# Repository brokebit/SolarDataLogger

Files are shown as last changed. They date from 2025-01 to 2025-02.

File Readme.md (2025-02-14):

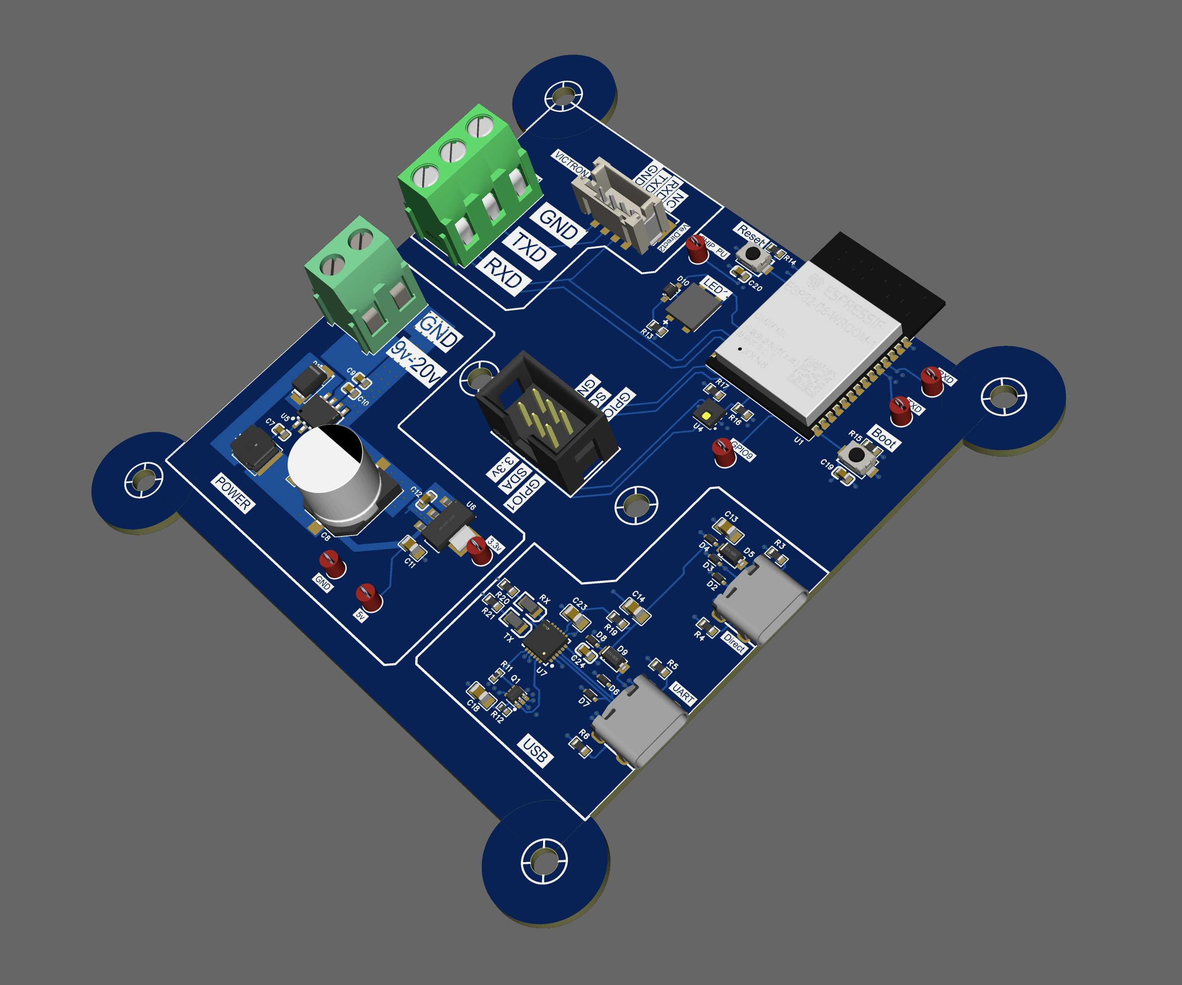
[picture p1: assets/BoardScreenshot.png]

# This repo has submodules
- To clone: git clone --recurse-submodules -j8 REPO_URL
- To pull latest versin: git pull --recurse-submodules

# What is all this

Firmware for custom data logger for Victron MPPT charge controllers via the Ve.Direct port/protocol.

## Features
- Power via 9v-20v input or USB
- ESP32-C6 RISC-V CPU
- Wifi 6 support and provisioning credentials via BLE
- Receive, parse, and publish data from a Victron MPPT controller
- Publishes: panel voltage, battery voltage, panel current, battery current, serial number, etc
- Publish data via MQTT in InfluxDB line protocol format
- Onboard temperature and humidity sensors (AHT20)
- Support for optional add on board with current sensor (INA226) and solid state relay (CMX60D10)
- WS2812 LED for status information
- CP2102N USB Uart for programing and logging
- USB port direct to ESP32-C6
- Remote control via MQTT command channel

## Supported Victron MPPT Controllers

Supports both the smaller MPPT controllers that have load output and control:

- MPPT 75/10
- MPPT 75/15
- MPPT 100/10
- MPPT 100/20

Also support larger MPPT controllers without load output via a INA226 Current sensor on an add-on board:

- MPPT 100/30
- MPPT 100/50
- MPPT 150/35
- MPPT 150/45
- MPPT 150/60
- MPPT 250/70

## The Details
This is a Platform IO project. Last tested with ESP IDF 5.3.1

- /lib contains drivers and victron parser
- /src contains main program

Edit platform.ini to set some global variables and config parameters. 
- INA226_PRESENT: Set this to one if you have a INA226 connected. Otherwise 0. 
- AHT20_PRESENT: Set this to 1 if you have a AHT20 connected. Otherwise 0.
- SENSOR_LOCATION: Set this to any string you want. It will be included in the mqtt message. No more than 24 characters
- SENSOR_TYPE: Set this to whatever you want. i.e. ESP32-C6 or ESP32-S3. No more than 24 characters
           

# MQTT

## Channels
- Influx data is sent to MQTT_TOPIC
- Command should be submitted to the channel named mac address + "-cmd" i.e. FFEEDDCCBBAA-cmd 
- Commands responses are sent to the channel named mac address. i.e. FFEEDDCCBBAA

## Support remote MQTT Commands
- ota - Perform an OTA Update
- rbk - Roll back to previous version 
- rst - Reboot
- png - Get a pong back
- tmp - Get current temp in C
- hum - Get current humidity
- mem - Get free heap memory
- ver - Get firmware version

# OTA
- Firmware is download via https from any URL. The firmware looks for a file that is the mac address in all caps. 
- Firmware URL is defined in : OTA_BASE_URL (without the filename)
- Rememeber you need to configure partitions.csv 1mb partition is not enough. 

# WiFi Provisioning
- To make a QR Code for provisioning use the following JSON string and fill in appropriate values:
```{"ver":"v1","name":"PROV_123456","pop":"abcd12345","transport":"ble"}```
- Use the mobile app called "ESP BLE Provisioning"
- In menuconfig make sure that: Component config -> Bluetooth -> Bluetooth controller -> Controller Options is set to BLE not Dual Mode.

# What can you do with it? 

## Grafana Dashboard Example
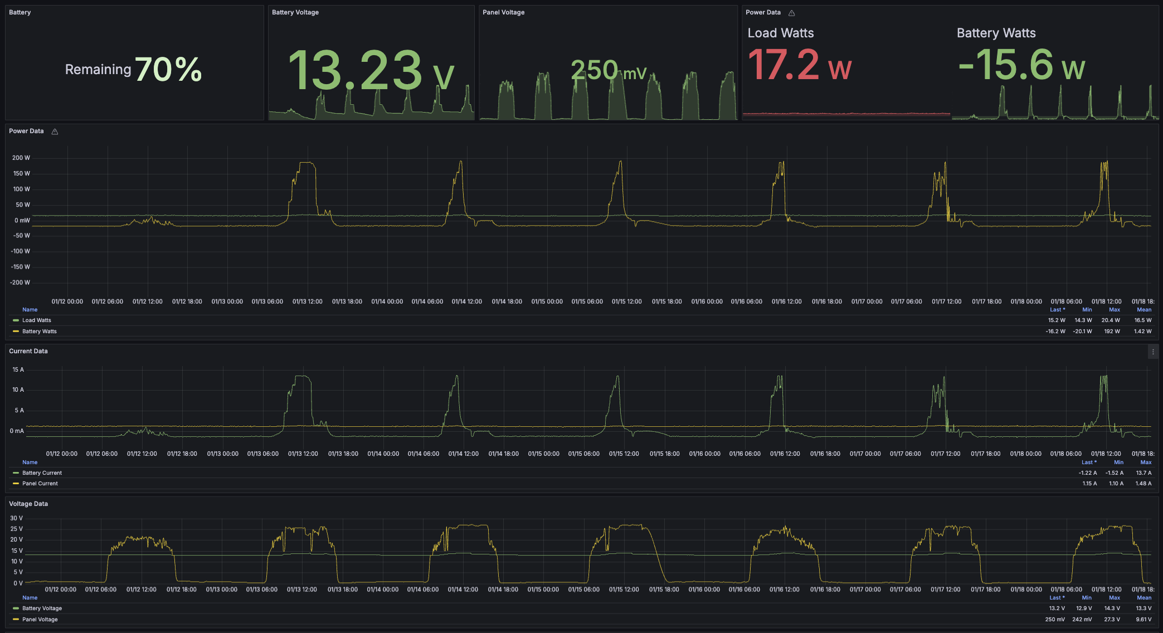
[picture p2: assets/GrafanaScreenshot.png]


# To Do
- Fix math for INA226 current sensor and address twos compliment
- CMX60D10 Relay Driver
- Some way to configure it without recompiling 
- Redo design in KiCad instead of EasyEDA and add to repo
- Finish add onboard with INA226 and CMX60D10
- Code clean up. Comments, proper error handling, review memory managment, null point checks, etc
- Add remote commands for reading voltage and current data
- MQTT TLS Support

# Done
- WS2812 Driver
- OTA Updates
- Wifi Provisioning via BLE

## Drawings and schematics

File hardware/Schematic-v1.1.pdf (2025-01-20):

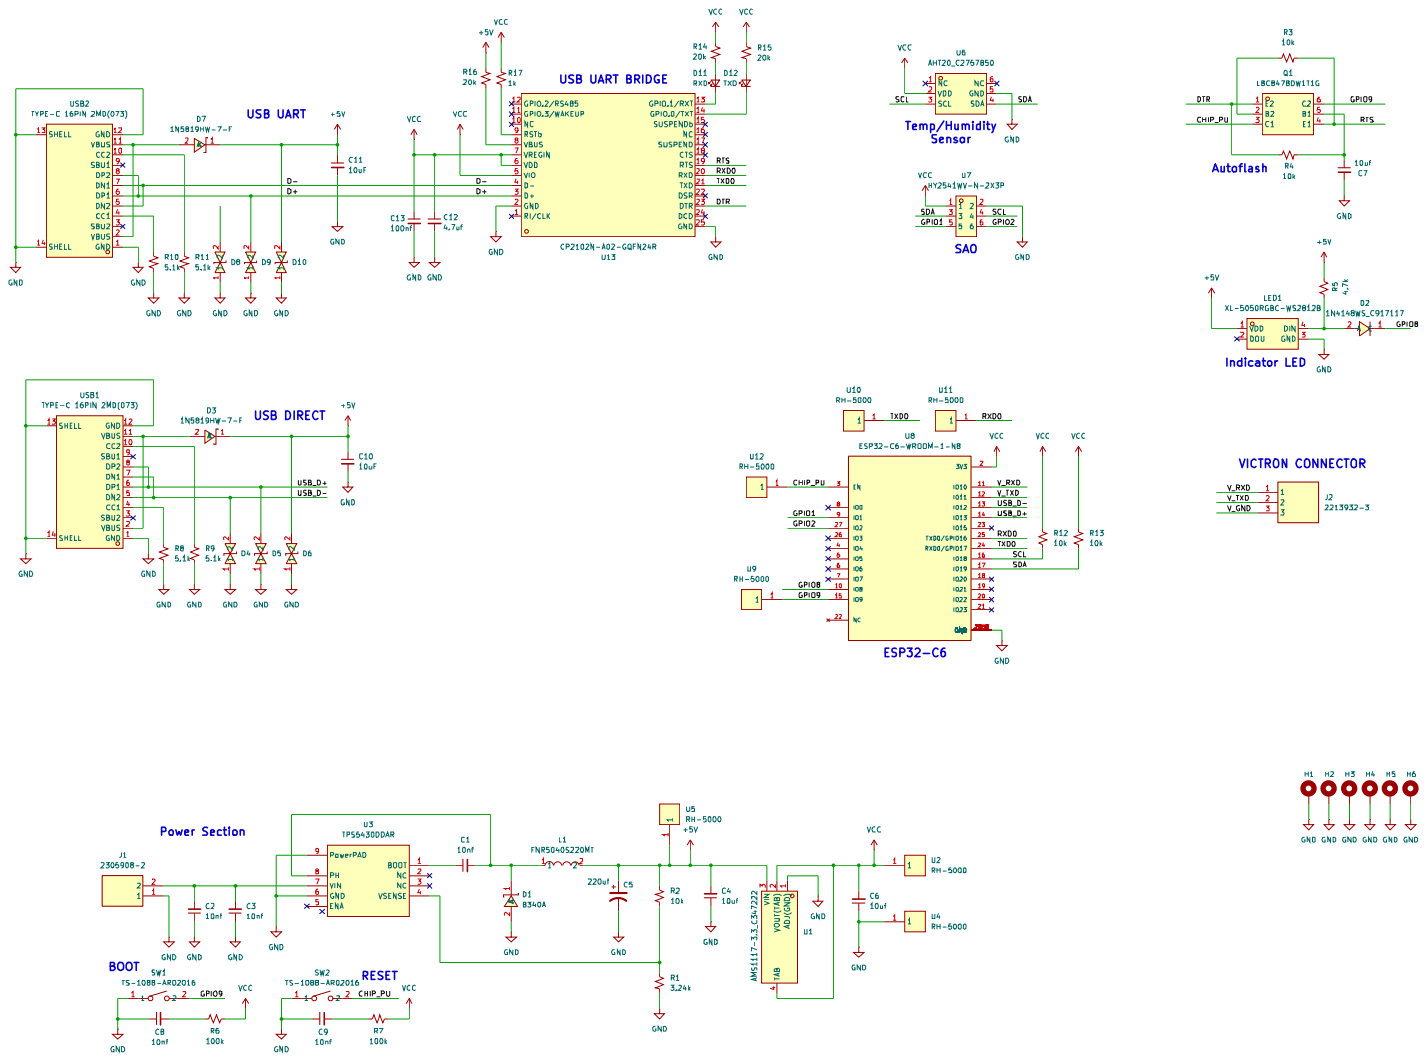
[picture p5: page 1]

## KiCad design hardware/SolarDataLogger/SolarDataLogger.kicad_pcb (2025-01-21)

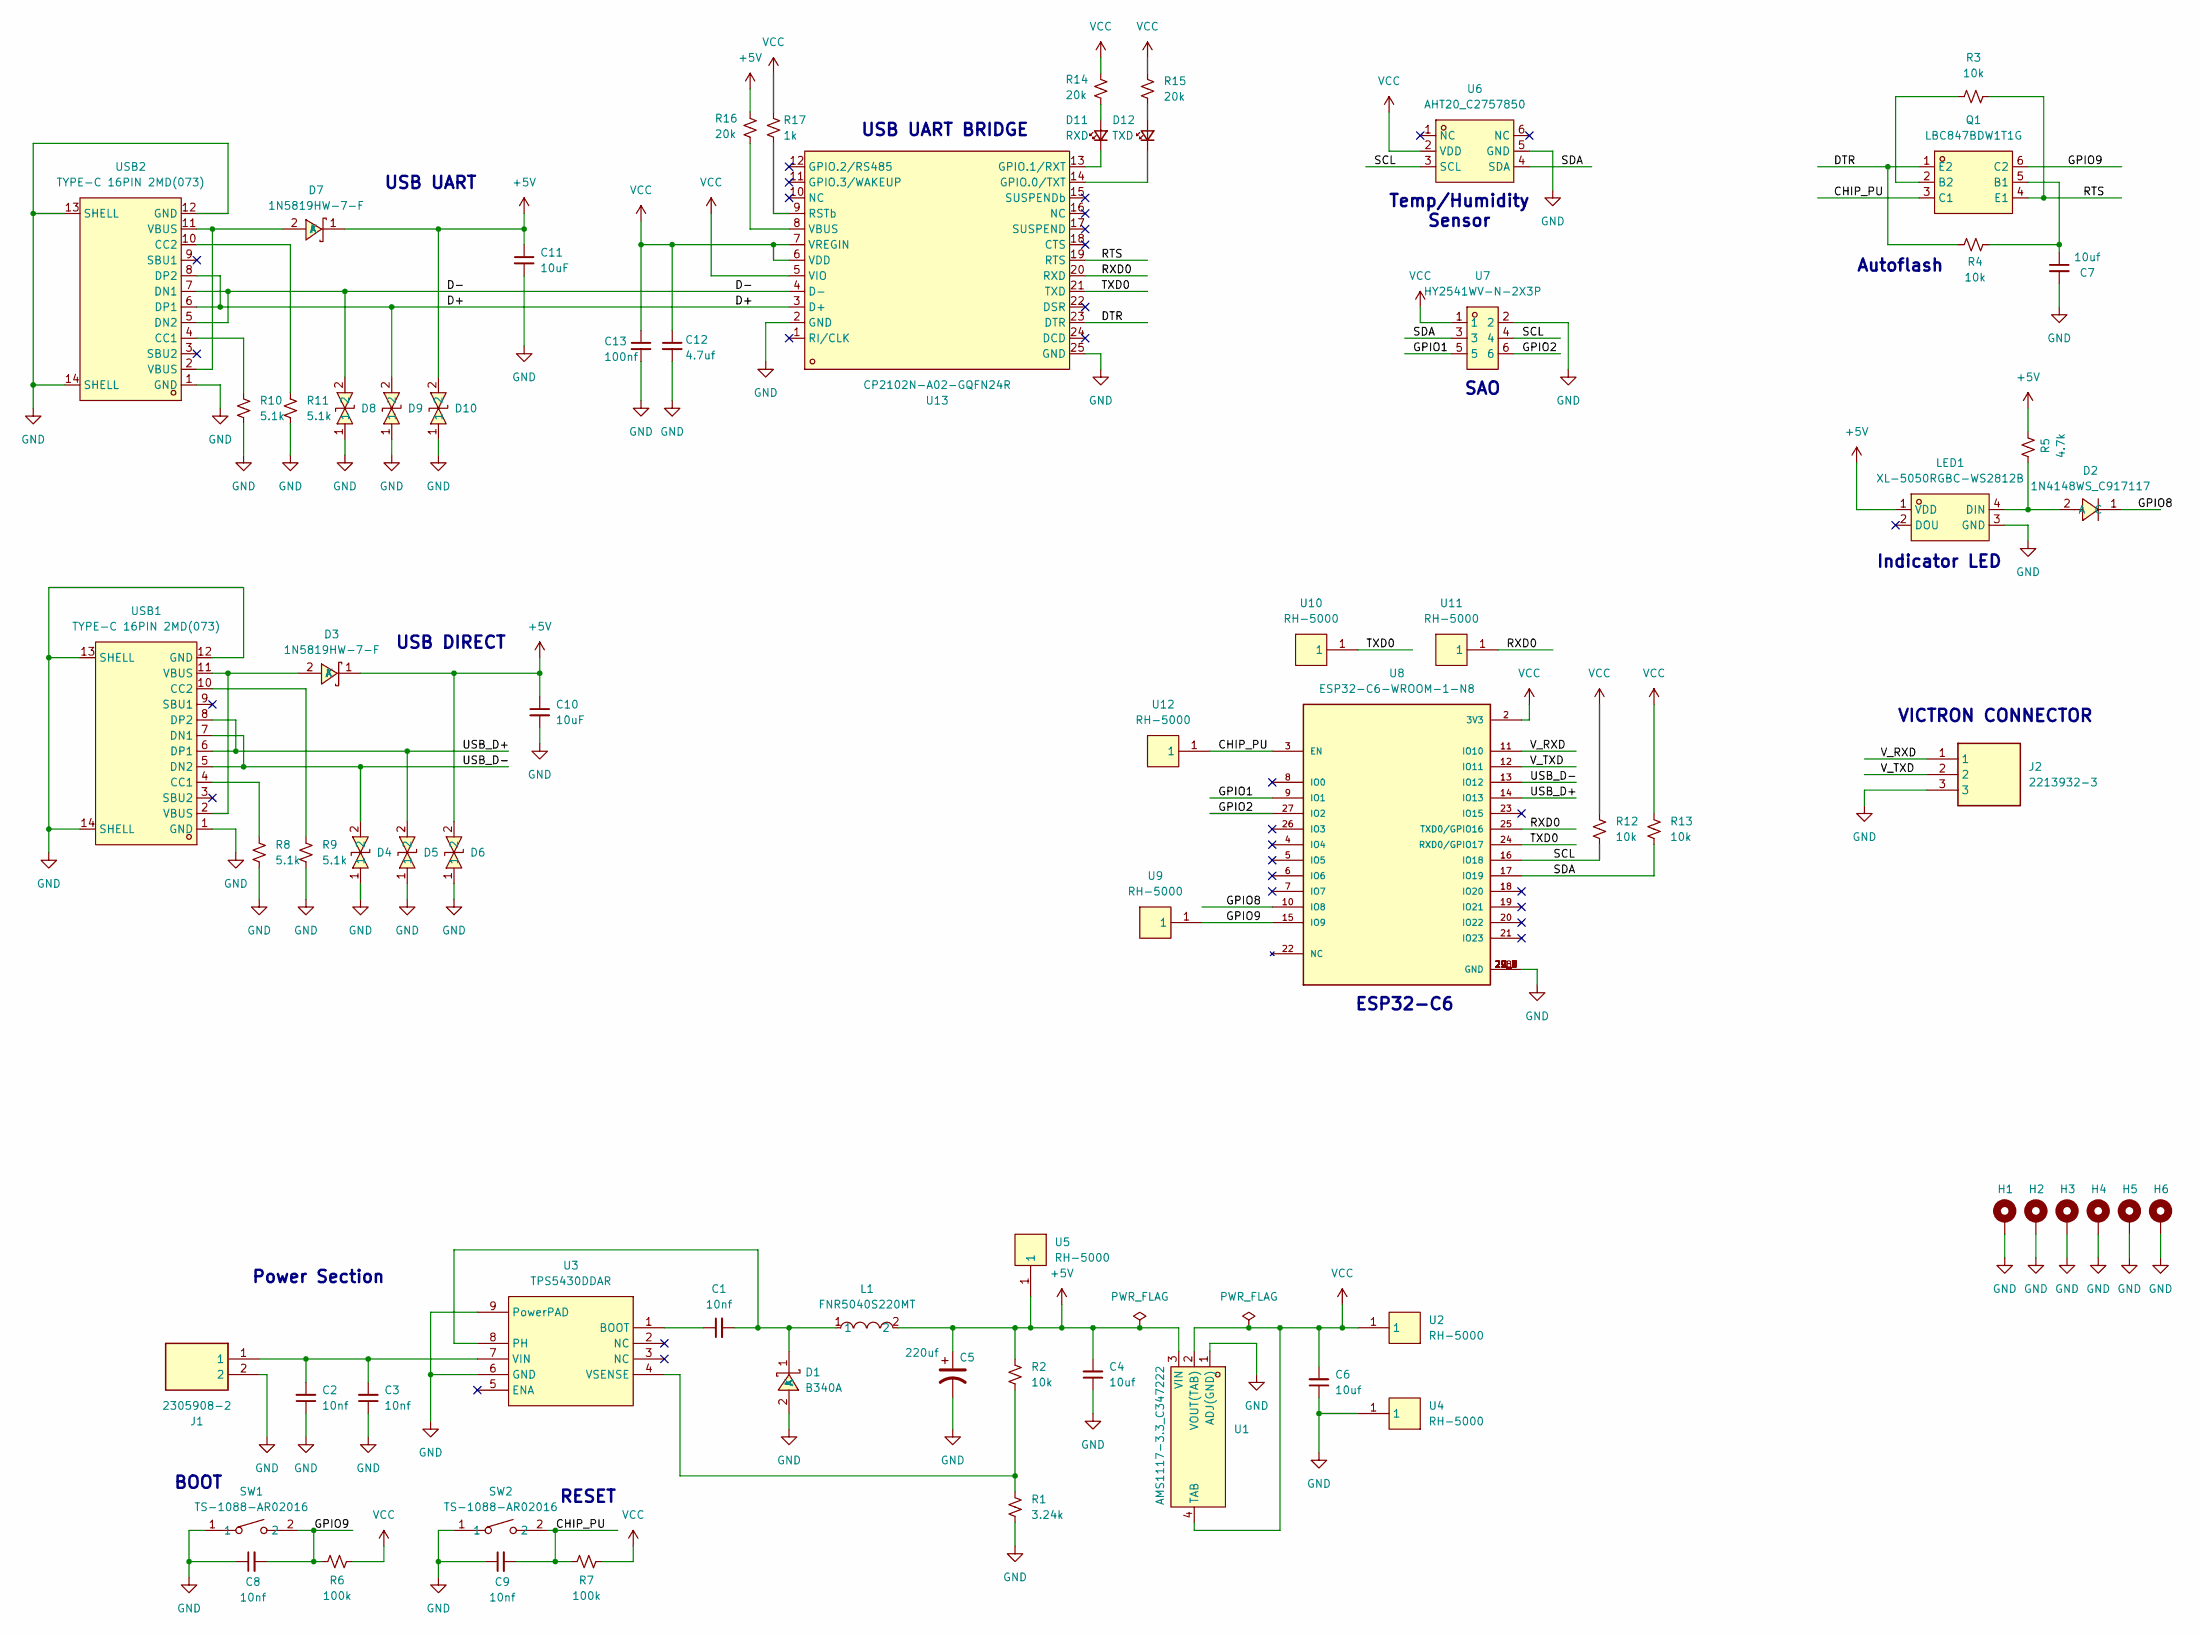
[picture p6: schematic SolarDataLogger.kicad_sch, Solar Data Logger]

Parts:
C1, C2, C3, C8, C9: 10nf; C_0603_1608Metric
C4, C6, C7: 10uf; C_0603_1608Metric
C5: 220uf; CAP-SMD_BD10.0-L10.3-W10.3-LS11.3-FD
C10, C11: 10uF; C_0603_1608Metric
C12: 4.7uf; C_0603_1608Metric
C13: 100nf; C_0603_1608Metric
D1: B340A; SMA_L4.3-W2.6-LS5.1-RD; LCSC Part C64982
D2: 1N4148WS_C917117; SOD-323_L1.8-W1.3-LS2.5-RD; LCSC Part C917117
D3, D7: 1N5819HW-7-F; SOD-123_L2.7-W1.6-LS3.7-RD; LCSC Part C82544
D4, D5, D6, D8, D9, D10: LESD5D5.0CT1G; SOD-523_L1.2-W0.8-LS1.6-BI; LCSC Part C383211
D11: RXD; LED_0603_1608Metric
D12: TXD; LED_0603_1608Metric
H1, H2, H3, H4, H5, H6: MountingHole_Pad; MountingHole_3.5mm_Pad_TopBottom
J1: 2305908-2; 23059082; Mouser Part Number 571-2305908-2
J2: 2213932-3; 22139323; Mouser Part Number 571-2213932-3
L1: FNR5040S220MT; IND-SMD_L5.0-W5.0; LCSC Part C167971
LED1: XL-5050RGBC-WS2812B; LED-SMD_4P-L5.0-W5.0-BL_XL-5050RGBC; LCSC Part C2843785
Q1: LBC847BDW1T1G; SOT-363_L2.0-W1.3-P0.65-LS2.1-BR; LCSC Part C383191
R1: 3.24k; R_0603_1608Metric
R2, R3, R4, R12, R13: 10k; R_0603_1608Metric
R5: 4.7k; R_0603_1608Metric
R6, R7: 100k; R_0603_1608Metric
R8, R9, R10, R11: 5.1k; R_0603_1608Metric
R14, R15, R16: 20k; R_0603_1608Metric
R17: 1k; R_0603_1608Metric
SW1, SW2: TS-1088-AR02016; SW-SMD_L3.9-W3.0-P4.45; LCSC Part C720477
U1: AMS1117-3.3_C347222; SOT-223-4_L6.5-W3.5-P2.30-LS7.0-BR; LCSC Part C347222
U2, U4, U5, U9, U10, U11, U12: RH-5000; TEST-TH_BD2.54-P1.4_RED; LCSC Part C5277086
U3: TPS5430DDAR; ESOP-8_L4.9-W3.9-P1.27-LS6.0-TL-EP; LCSC Part C9864
U6: AHT20_C2757850; SENSOR-SMD_L3.0-W3.0-P1.00-BR; LCSC Part C2757850
U7: HY2541WV-N-2X3P; IDC-Header_2x03_P2.54mm_Vertical_SMD; LCSC Part C17179450
U8: ESP32-C6-WROOM-1-N8; XCVR_ESP32-C6-WROOM-1-N8; PARTREV 1.0
U13: CP2102N-A02-GQFN24R; QFN-24_L4.0-W4.0-P0.50-TL-EP2.6; LCSC Part C969151
USB1, USB2: TYPE-C 16PIN 2MD(073); USB-C-SMD_TYPE-C-6PIN-2MD-073; LCSC Part C2765186

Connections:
+5V: C4.2, C5.1, C10.1, C11.1, D3.1 (K), D6.2, D7.1 (K), D10.2, L1.2, LED1.1 (VDD), R2.1, R5.1, R16.1, U1.3 (VIN), U5.1
/CHIP_PU: C9.2, Q1.3 (C1), R7.1, SW2.2, U8.3 (EN), U12.1
/D+: D9.2, U13.3 (D+), USB2.6 (DP1), USB2.8 (DP2)
/D-: D8.2, U13.4 (D-), USB2.5 (DN2), USB2.7 (DN1)
/DTR: Q1.1 (E2), R4.2, U13.23 (DTR)
/GPIO1: U7.5, U8.9 (IO1)
/GPIO2: U7.6, U8.27 (IO2)
/GPIO8: D2.1 (C), U8.10 (IO8)
/GPIO9: C8.2, Q1.6 (C2), R6.1, SW1.2, U8.15 (IO9), U9.1
/RTS: Q1.4 (E1), R3.2, U13.19 (RTS)
/RXD0: U8.25 (TXD0/GPIO16), U11.1, U13.20 (RXD)
/SCL: R12.1, U6.3 (SCL), U7.4, U8.16 (IO18)
/SDA: R13.1, U6.4 (SDA), U7.3, U8.17 (IO19)
/TXD0: U8.24 (RXD0/GPIO17), U10.1, U13.21 (TXD)
/USB_D+: D5.2, U8.14 (IO13), USB1.6 (DP1), USB1.8 (DP2)
/USB_D-: D4.2, U8.13 (IO12), USB1.5 (DN2), USB1.7 (DN1)
/V_RXD: J2.1, U8.11 (IO10)
/V_TXD: J2.2, U8.12 (IO11)
GND: C2.1, C3.1, C4.1, C5.2, C6.1, C7.2, C8.1, C9.1, C10.2, C11.2, C12.2, C13.2, D1.2 (A), D4.1, D5.1, D6.1, D8.1, D9.1, D10.1, H1.1, H2.1, H3.1, H4.1, H5.1, H6.1, J1.2, J2.3, LED1.3 (GND), R1.2, R8.2, R9.2, R10.2, R11.2, SW1.1, SW2.1, U1.1 (ADJ(GND)), U3.6 (GND), U3.9 (PowerPAD), U4.1, U6.5 (GND), U7.2, U8.1 (GND), U8.28 (GND), U8.29_1 (GND), U8.29_2 (GND), U8.29_3 (GND), U8.29_4 (GND), U8.29_5 (GND), U8.29_6 (GND), U8.29_7 (GND), U8.29_8 (GND), U8.29_9 (GND), U13.2 (GND), U13.25 (GND), USB1.1 (GND), USB1.12 (GND), USB1.13 (SHELL), USB1.14 (SHELL), USB2.1 (GND), USB2.12 (GND), USB2.13 (SHELL), USB2.14 (SHELL)
unnamed: C1.2, D1.1 (K), L1.1, U3.8 (PH)
unnamed: D2.2 (A), LED1.4 (DIN), R5.2
unnamed: D3.2 (A), USB1.2 (VBUS), USB1.11 (VBUS)
unnamed: D7.2 (A), USB2.2 (VBUS), USB2.11 (VBUS)
unnamed: D11.2 (A), R14.2
unnamed: D11.1 (K), U13.13 (GPIO.1/RXT)
unnamed: D12.2 (A), R15.2
unnamed: D12.1 (K), U13.14 (GPIO.0/TXT)
unnamed: C7.1, Q1.5 (B1), R4.1
unnamed: Q1.2 (B2), R3.1
unnamed: C1.1, U3.1 (BOOT)
unnamed: C2.2, C3.2, J1.1, U3.7 (VIN)
unnamed: R1.1, R2.2, U3.4 (VSENSE)
unnamed: R17.2, U13.9 (RSTb)
unnamed: R16.2, U13.8 (VBUS)
unnamed: R8.1, USB1.4 (CC1)
unnamed: R9.1, USB1.10 (CC2)
unnamed: R10.1, USB2.4 (CC1)
unnamed: R11.1, USB2.10 (CC2)
VCC: C6.2, C12.1, C13.1, R6.2, R7.2, R12.2, R13.2, R14.1, R15.1, R17.1, U1.2 (VOUT(TAB)), U1.4 (TAB), U2.1, U6.2 (VDD), U7.1, U8.2 (3V3), U13.5 (VIO), U13.6 (VDD), U13.7 (VREGIN)

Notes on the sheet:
Power Section
Indicator LED
USB UART BRIDGE
SAO
USB DIRECT
USB UART
VICTRON CONNECTOR
ESP32-C6
RESET
BOOT
Autoflash
Temp/Humidity Sensor

Board: 6 copper layers, 70 parts (0 on the bottom side), 39 nets, no tracks yet.

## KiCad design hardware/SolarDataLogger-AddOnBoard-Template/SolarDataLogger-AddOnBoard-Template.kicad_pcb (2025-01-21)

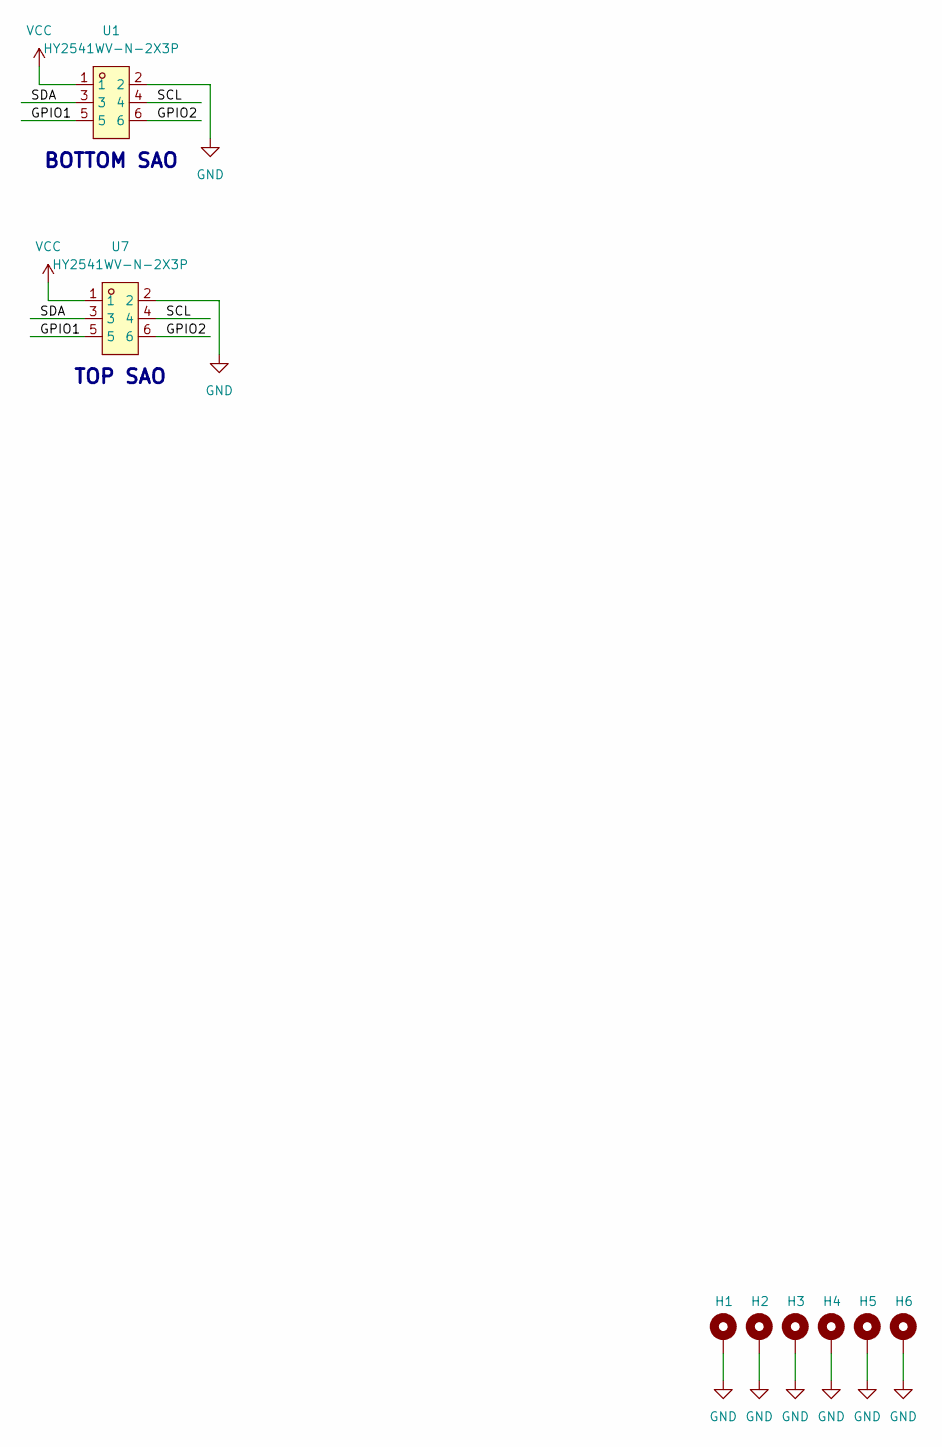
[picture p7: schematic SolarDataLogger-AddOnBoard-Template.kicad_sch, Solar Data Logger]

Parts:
H1, H2, H3, H4, H5, H6: MountingHole_Pad; MountingHole_3.5mm_Pad_TopBottom
U1: HY2541WV-N-2X3P; PinSocket_2x03_P2.54mm_Vertical_SMD; LCSC Part C17179450
U7: HY2541WV-N-2X3P; IDC-Header_2x03_P2.54mm_Vertical_SMD; LCSC Part C17179450

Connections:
/GPIO1: U1.5, U7.5
/GPIO2: U1.6, U7.6
/SCL: U1.4, U7.4
/SDA: U1.3, U7.3
GND: H1.1, H2.1, H3.1, H4.1, H5.1, H6.1, U1.2, U7.2
VCC: U1.1, U7.1

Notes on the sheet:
TOP SAO
BOTTOM SAO

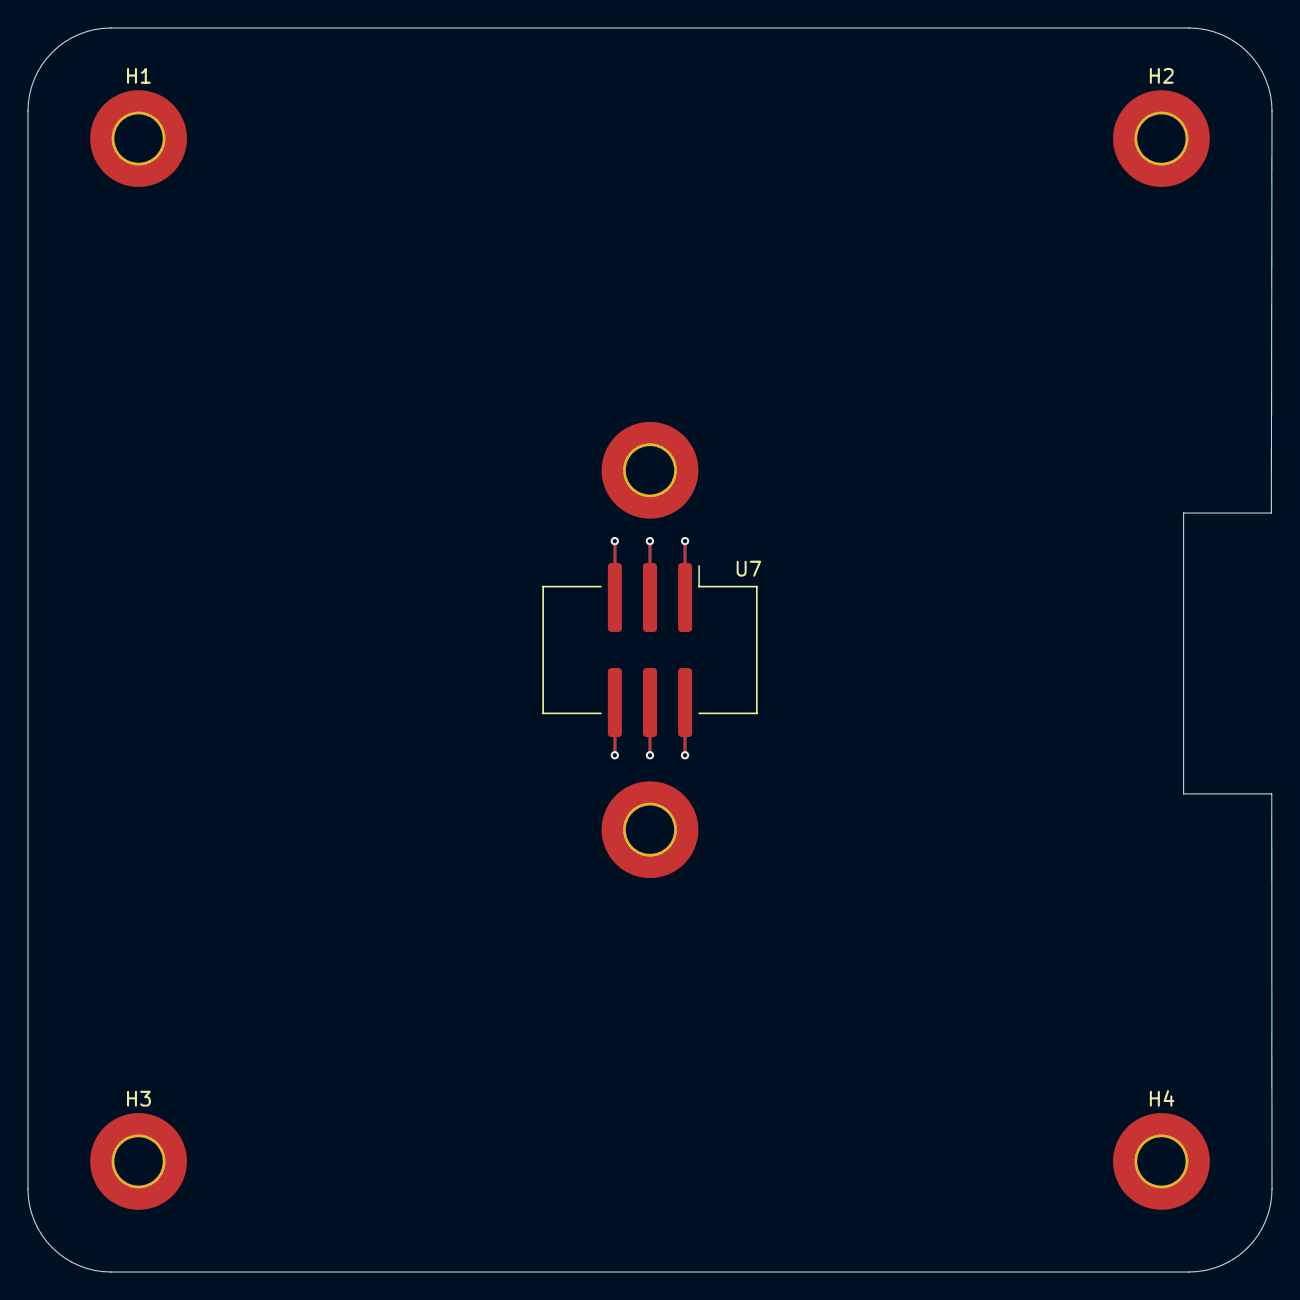
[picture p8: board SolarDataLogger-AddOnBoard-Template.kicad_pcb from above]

Board: 6 copper layers, 90.0 x 90.0 mm, 8 parts (1 on the bottom side), 6 nets.

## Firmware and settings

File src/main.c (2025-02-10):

#include <stdio.h>
#include <stdint.h>
#include <stddef.h>
#include <string.h>
#include "freertos/FreeRTOS.h"
#include "freertos/task.h"
#include "freertos/event_groups.h"
#include "freertos/semphr.h"
#include "freertos/queue.h"
#include "driver/gpio.h"

#include "esp_system.h"
#include "esp_wifi.h"
#include "esp_event.h"
#include "esp_log.h"
#include "nvs_flash.h"
#include "esp_netif.h"
#include "esp_mac.h"

#include "lwip/err.h"
#include "lwip/sys.h"
#include "lwip/sockets.h"
#include "lwip/dns.h"
#include "lwip/netdb.h"

#include "wifi.h"

#include "driver/i2c_master.h"
#include "mqtt.h"
#include "ota.h"
#include "esp_ws28xx.h"

#define FIRMWARE_VERSION "1.1.4"
#define SENSOR_LOCATION "alley"
#define SENSOR_TYPE "esp32c6"

// #define GPIO1_CTL CONFIG_GPIO_INPUT_1
// #define GPIO2_CTL CONFIG_GPIO_INPUT_2

#define LED_GPIO 8
#define SDA_GPIO 18
#define SCL_GPIO 19

// Interval in which to publish MQTT Data in seconds (This is approximate due to processing time and such)
#define MQTT_PUBLISH_INTERVAL 60
#define MQTT_TOPIC         "sensors_beta"
#define QUEUE_REFILL_WAIT 3000
#define CONFIG_BROKER_URL "mqtt://192.168.100.20"

#if (INA226_PRESENT == 1) || (AHT20_PRESENT == 1)
    #include "my-i2c.h"
    i2c_master_bus_handle_t i2c_bus_handle;

#endif

#if INA226_PRESENT == 1
    #include "ina226.h"
    INA226_DATA ina226_data;
#endif 

#if AHT20_PRESENT == 1
    #include "aht20.h"
    AHT20_DATA aht20_data;
#endif

#include <victron.h>
#include "secrets.h"

CRGB* ws2812_buffer;
static const char *TAG = "Main-Task";
static char my_mac[13];
static EventGroupHandle_t s_wifi_event_group;

void app_main(void) {

    esp_err_t ret = nvs_flash_init();
    if (ret == ESP_ERR_NVS_NO_FREE_PAGES || ret == ESP_ERR_NVS_NEW_VERSION_FOUND) {
      ESP_ERROR_CHECK(nvs_flash_erase());
      ret = nvs_flash_init();
    }
    ESP_ERROR_CHECK(ret);

    s_wifi_event_group = xEventGroupCreate();

    ESP_ERROR_CHECK_WITHOUT_ABORT(ws28xx_init(LED_GPIO, WS2812B, 1, &ws2812_buffer));
    ws2812_buffer[0] = (CRGB){.r=25, .g=8, .b=0};
    ESP_ERROR_CHECK_WITHOUT_ABORT(ws28xx_update());

    vTaskDelay(2000 / portTICK_PERIOD_MS); // debug delay

    uint8_t mac[6];
    esp_base_mac_addr_get(mac);
    snprintf(my_mac, 13, "%02X%02X%02X%02X%02X%02X",
             mac[0], mac[1], mac[2], mac[3], mac[4], mac[5]);

    ESP_LOGI("TAG", "MAC Address: %s", my_mac);

    MY_MQTT_DATA *my_mqtt_data = malloc(sizeof(MY_MQTT_DATA));
    

    my_mqtt_data->broker_url = CONFIG_BROKER_URL;
    my_mqtt_data->topic = MQTT_TOPIC;
    my_mqtt_data->sensor_location = SENSOR_LOCATION;
    my_mqtt_data->sensor_type = SENSOR_TYPE;
    my_mqtt_data->publish_interval = MQTT_PUBLISH_INTERVAL;
    my_mqtt_data->queue_refill_wait = QUEUE_REFILL_WAIT;
    my_mqtt_data->xQueue_mqtt = xQueueCreate( 2, sizeof( struct SolarData));
    my_mqtt_data->mac = my_mac;
    my_mqtt_data->fmw_version = FIRMWARE_VERSION;

    #if (INA226_PRESENT == 1) || (AHT20_PRESENT == 1)
        ESP_LOGI(TAG, "At least one of INA226 or AHT20 is present and I2C driver is included.");
        my_i2c_init(I2C_CONTROLLER_0, 19, 18, &i2c_bus_handle);
    #endif
    
    #if (INA226_PRESENT == 1)
        ina226_data.bus_handle = i2c_bus_handle;
        ina226_init(&ina226_data);
        my_mqtt_data->ina226_data = ina226_data;
	#endif

    #if (AHT20_PRESENT == 1)
        aht20_data.bus_handle = i2c_bus_handle;
        aht20_init(&aht20_data);
        my_mqtt_data->aht20_data = aht20_data;
    #endif

    ESP_LOGI(TAG, "Initializing Wifi");
    wifi_init(s_wifi_event_group);
    
    if (my_mqtt_data->xQueue_mqtt == NULL) { 
        ESP_LOGE(TAG, "Error creating the queue");
        return;
    }

    xEventGroupWaitBits(s_wifi_event_group, WIFI_CONNECTED_BIT, false, true, portMAX_DELAY);
    mqtt_init(my_mqtt_data);

    xTaskCreate(recieve_serial, "recieve_serial", 4096, (void *)my_mqtt_data->xQueue_mqtt, 1, NULL);
    xTaskCreate(mqtt_app_start, "mqtt_app_start", 4096, (void *)my_mqtt_data, 1, NULL);

    mqtt_publish(my_mqtt_data->client, my_mac, FIRMWARE_VERSION);

    ws2812_buffer[0] = (CRGB){.r=0, .g=5, .b=0};
    ESP_ERROR_CHECK_WITHOUT_ABORT(ws28xx_update());

    ESP_LOGI(TAG, "Firmware Version: %s", FIRMWARE_VERSION);

    gpio_dump_io_configuration(stdout, (1ULL << 1) |(1ULL << 2));

    gpio_config_t gpio_cfg = {};
    gpio_cfg.intr_type = GPIO_INTR_DISABLE;
    gpio_cfg.mode = GPIO_MODE_OUTPUT;
    gpio_cfg.pin_bit_mask = ((1ULL << 1)|(1ULL << 2));
    gpio_cfg.pull_down_en = 1;
    gpio_cfg.pull_up_en = 0;
    gpio_config(&gpio_cfg);
    
    gpio_dump_io_configuration(stdout, (1ULL << 1) |(1ULL << 2));
    
}

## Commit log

2025-01-20 Migrating to KiCad Manually
    [SolarDataLogger.kicad_pcb, SolarDataLogger.kicad_sch]
2025-01-20 Moving along
    [SolarDataLogger.kicad_pcb, SolarDataLogger.kicad_sch]
2025-01-20 Add WS28xx driver as a git submodule
2025-01-20 Increase partition sizes. Add LED driver and code
    [partitions.csv]
2025-01-20 Update schematic because I wanted to
2025-01-21 The work must be done
    [SolarDataLogger.kicad_pcb, SolarDataLogger.kicad_sch]
2025-01-21 Templates for all!
    [SolarDataLogger-AddOnBoard-Template.kicad_pcb, SolarDataLogger-AddOnBoard-Template.kicad_sch, SolarDataLogger.kicad_pcb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]
2025-02-14 It's raining a lot
    [SolarDataLogger.kicad_sch]
